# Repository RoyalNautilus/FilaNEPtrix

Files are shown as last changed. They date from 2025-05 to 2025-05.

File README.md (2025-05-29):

# FilaNEPtrix
This is a mod inspired by several projects to create a toolhead filament cutter for Neptune 4 and 4 Pro printers. This allows reliable and consistent multi-material and multicolor printing when paired with a MMU such as the [Box Turtle](https://github.com/ArmoredTurtle/BoxTurtle), [ERCF](https://github.com/Enraged-Rabbit-Community/ERCF_v2), [Pico MMU](https://github.com/lhndo/LH-Stinger/wiki/Pico-MMU), or others.

  * Please note that this is an *extremely* early release. Further optimization, iteration, and testing will be done over the next few weeks to hopefully turn this project into a stable and relatively hassle-free upgrade. 
  * If you have questions, would like to make suggestions, or notice any glaring issues to be resolved, please open an issue and let me know so I can get to work on it!
  
### Compatibility Note:
This was originally designed as a personal upgrade for my Neptune 4 Pro. While other models of Neptune 4 (or even Neptune 3) may function, alignment, tolerances, and features may differ just enough that the cutter may not operate as intended. Use at your own risk if you decide to try this on one of the other models!

## Gallery
*coming soon™*

## Recommended (and required) Paired Upgrades
### Toolhead Shroud - *MANDATORY*
Though there are many variants of the [OrzOrzOrz v5/6 Fan Shroud](https://www.printables.com/model/711424-elegoo-neptune-4promaxplus-fan-shroud-v5 "Printables"), the [SilencedFrost version](https://www.printables.com/model/905447-sf-3x5015-neptune-4-fan-mod-shroud-optimized-enhan "Printables") is (IMO) the ultimate version out so far. With compatibility with Beacon probes, many options for ADXL mounts, and the top-mounted bowden coupler options, not to mention the *stellar* cooling performance, there's really no way to go wrong with the upgrade.

To address the "Mandatory" tag, this is to say that FilaNEPtrix can only be installed on a shroud with heatset inserts or a similar mounting solution positioned in the same places on the top of the toolhead as SilencedFrost's. This is typically a pair of M3x5mm heat-set inserts located 5.5mm behind the *center* of the filament inlet, spaced 55mm apart. This placement allows full operation of the filament inlet, extruder manual release trigger, and exposed gear on the top, as well as leaving room for cooling fans.

### X-Axis

With the cutting motion applying great forces to the x-axis motion system, several X-axis upgrades will greatly help to prevent belt skipping. 
 * First, [layer.shifted (@Lamarc)'s X-Axis Double Shear Mod](https://www.printables.com/model/1222791-neptune-44pro-x-axis-double-shear-motor-upgrade "Printables").
   * This mod helps attach the X-axis motor pulley on both ends, allowing more tension without damage and preventing twisting from happening. (Side-benefit, *much* greater input shaper acceleration values in my testing!)
   * This will also allow for 3rd-party stepper motor upgrades, unlocking potential for much more reliable performance in the cutting action.

## BOM
*coming soon™*

## Recommended Print Settings
*coming soon™*

## Assembly
*coming soon™*

## Software Config & Tuning
*coming soon™*

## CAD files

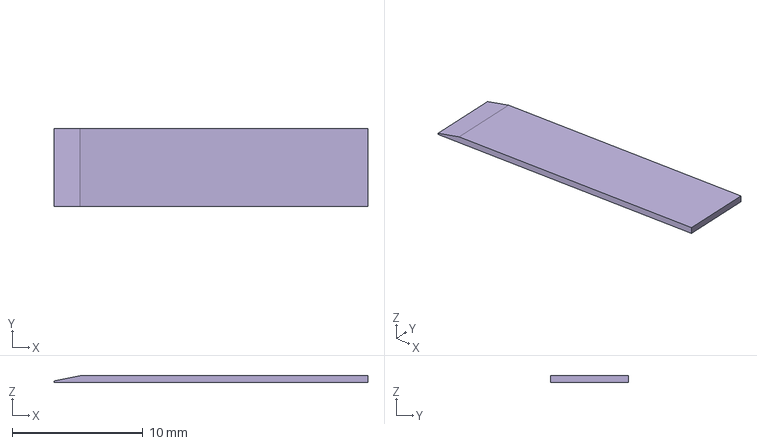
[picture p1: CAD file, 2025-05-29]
CAD/FilaNEPtrix.step
24.0 x 6.00 x 0.5 mm

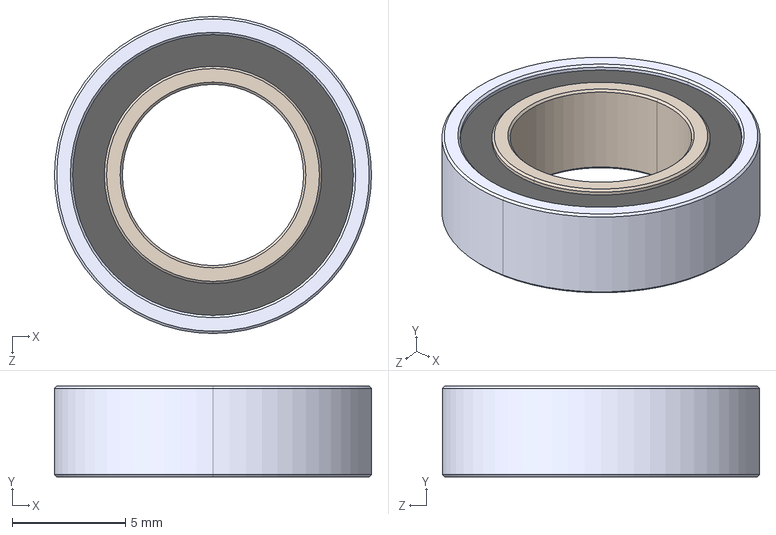
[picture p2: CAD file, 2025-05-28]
External Components/MR148-2RS Thrus Bearing- Thinhhouy.STEP
14.0 x 4.00 x 14.0 mm

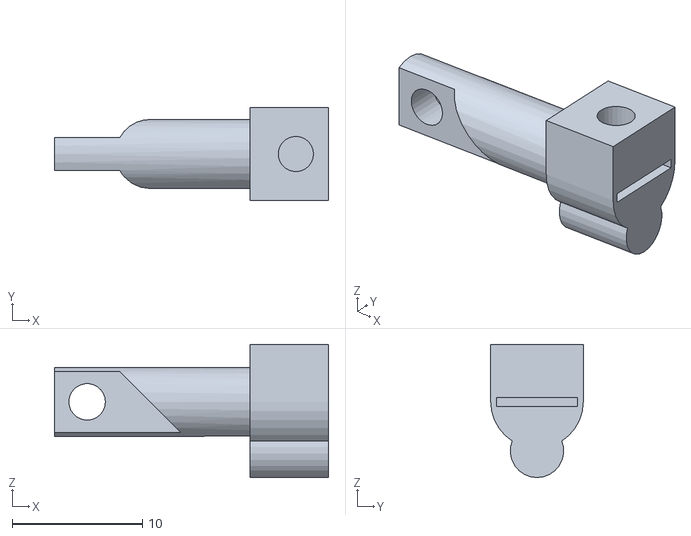
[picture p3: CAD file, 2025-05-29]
STLs/blade-mount-slider.stl
21.0 x 7.10 x 10.2

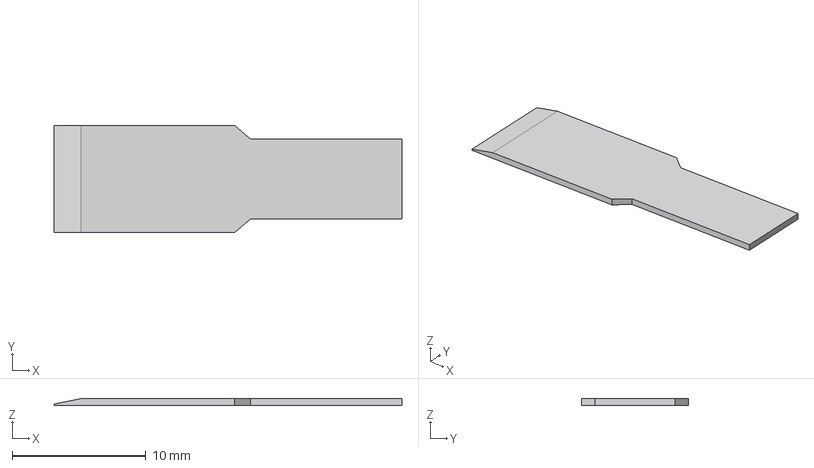
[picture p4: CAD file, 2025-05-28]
External Components/Hobby Knife Blade.step
26.0 x 8.00 x 0.5 mm

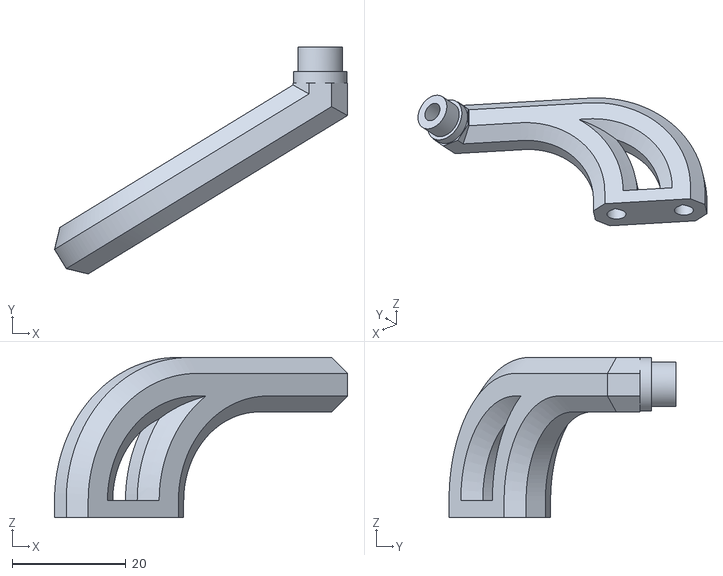
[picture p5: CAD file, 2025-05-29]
STLs/cutter-engager.stl
51.6 x 40.0 x 28.2

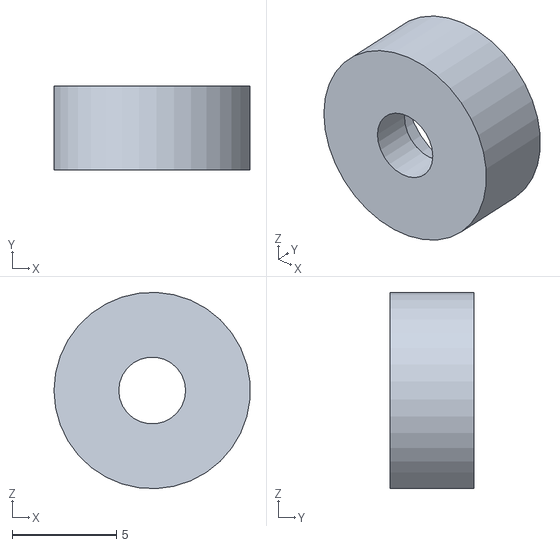
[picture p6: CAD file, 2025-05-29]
STLs/bearing-stopper.stl
9.38 x 4.00 x 9.39

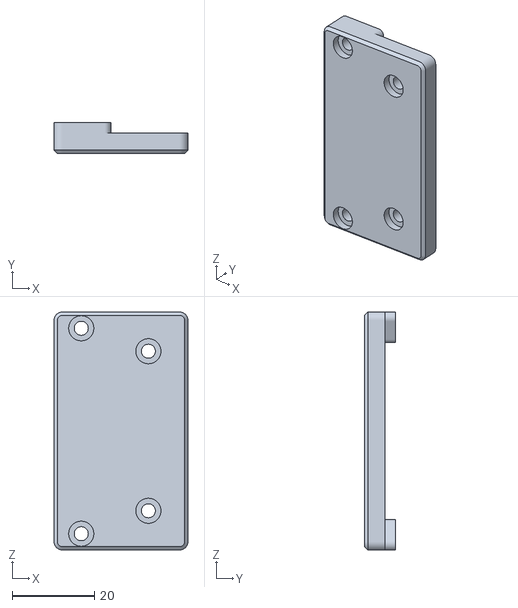
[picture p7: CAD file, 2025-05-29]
STLs/x-mount-back.stl
32.5 x 7.50 x 57.8

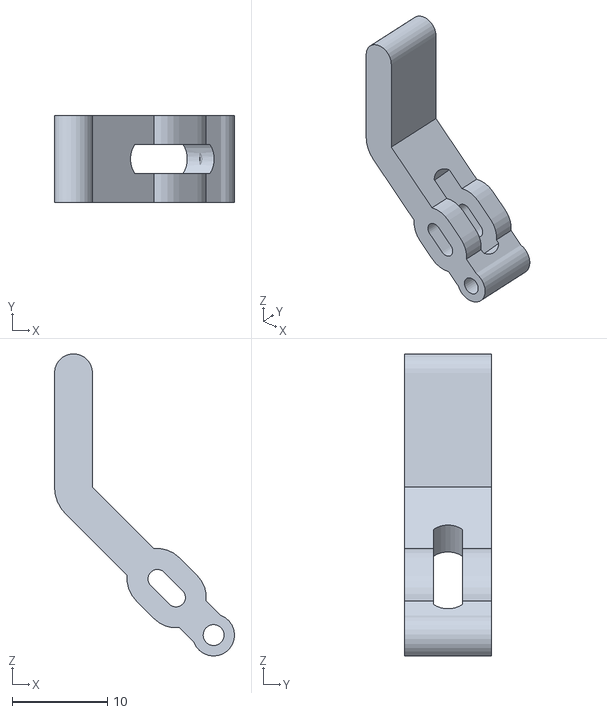
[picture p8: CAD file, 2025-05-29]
STLs/cutter-trigger.stl
18.9 x 9.10 x 31.7

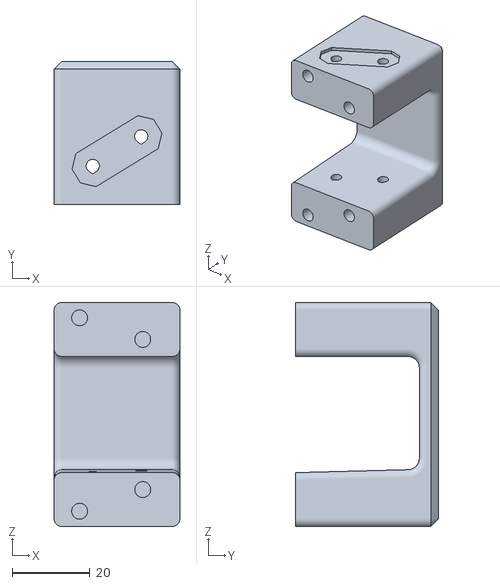
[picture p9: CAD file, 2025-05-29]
STLs/x-mount-front.stl
32.5 x 37.0 x 57.8

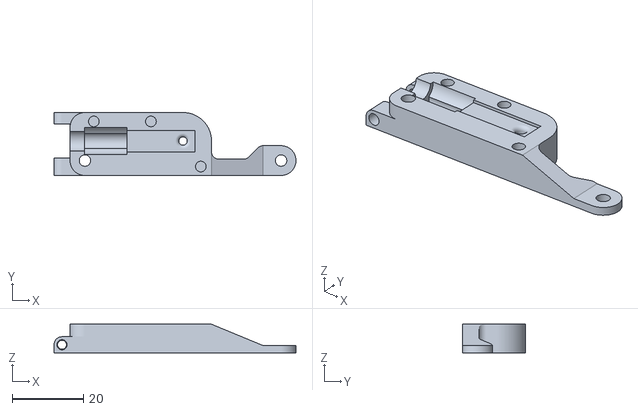
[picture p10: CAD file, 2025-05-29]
STLs/toolhead-mount.stl
67.9 x 17.6 x 8.00

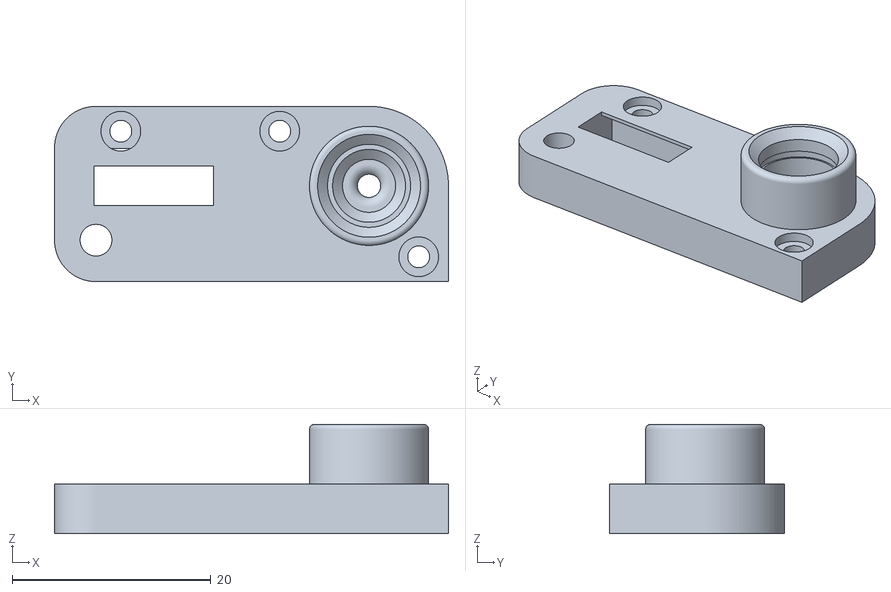
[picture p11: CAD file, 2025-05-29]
STLs/bowden-mount-ecas04.stl
39.7 x 17.6 x 11.0

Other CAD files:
CAD/FilaNEPtrix.FCStd

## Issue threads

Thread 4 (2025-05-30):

TODO: add more clearance for blade inside toolhead mount to allow complete tightening without binding the blade

RoyalNautilus, 2025-05-30:

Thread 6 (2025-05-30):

TODO: add servo option/compatibility to activate and deactivate cutter engager

RoyalNautilus, 2025-05-30:
Would allow for uninterrupted X-axis homing on the left side and remove the slight loss in build volume on the right side. Will need to see what's possible here.
Possible to re-use aux fan cable to make for an easy mod?

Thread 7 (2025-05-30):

TODO: N4Plus/Max variant

RoyalNautilus, 2025-05-30:
As I don't own either of these models, and Elegoo has made no CAD files for the N4 series, I will need somebody else to confirm dimensions and test

RoyalNautilus, 2025-07-24:
> Hey,
>
> I hope the project isn’t dead. I’m from Germany and using a translator, so I hope you still understand me correctly. I’m using the Neptune 4 Plus with the SilencedFrost fan shroud and the Pico MMU, and I’m currently testing your filament cutter, or rather, I’m still working on finishing the build properly. I’d love to contribute to the project. The dimensions seem to fit so far. However, I’m not sure how the lever is supposed to spring back on its own. Could you help me with that?

Hey!
It's not dead, I've just had an extremely busy couple of weeks at my day job.

I think I have the last iteration of design finished and ready to go that solves most of the issues I ran into previously. Just need to print it and test it out, then go through and fill out the BOM which I know is a big step missing at the moment.

To answer your question about the lever, there is a pocket in the toolhead-mount part that fits a small spring, before you insert the blade-mount-slider part. I believe the spring I used is from the FilamATtrix kit that came with my LDO Box Turtle kit, which looking at the BOM for that project seems to be a 0.5mm x 4mm x 25mm spring. According to those docs, a standard spring from a ball-point pen should be close enough to spec to be functional.

Hope that helps! I finally have a couple of free weekends coming up and will turn my attention back to finishing up all the missing parts of this project!

RoyalNautilus, 2025-07-24:
Also to note, I don't know how the dimensions of the Plus differ from the Pro, so the cutter-engager part may not line up exactly with the cutter-trigger as designed for the Pro.

derVampi, 2025-07-25:
Hey, thanks a lot for your reply! I'm glad to see things are moving forward and I'm excited about the upcoming improvements.

A spring? Why didn’t I think of that myself? 😅 I’ll give it a try. thanks in advance!
How can I help you with the measurements for the Neptune 4 Plus?
The lever isn’t perfectly centered, but it fits and cuts the filament when I move the printhead to the right.

derVampi, 2025-07-25:
The spring from a ballpoint pen fits perfectly. Thanks a lot for the tip! The cutting now works flawlessly. I just need to fine-tune it a bit so the filament change works automatically.

While doing that, I ran into a problem caused by my Eddy probe. During the bed level scan, the filament was cut. I temporarily solved it by slightly reducing the bed mesh on the X-axis.

derVampi, 2025-08-09:
Hey, everything's fine. I'm not the fastest at replying either 😅.

To be honest, I don't print that large, as I have the same warping issue with larger parts, so it doesn't bother me. It would probably work better with a closed build chamber.

The filament cutter is working perfectly at the moment. I just need to solve a few issues to ensure the filament passes the sensor, UBBI connector, etc. cleanly.

HutchMD, 2025-08-29:
I'm happy to see that there is hope for my dream of using my Neptune 4 Max with a Box Turtle.

I will be patiently waiting for a BoM list, and Assembly instructions!
Let me know if there's something I can do to help you test this on a N4 Max.

I am currently looking at shroud options that can fit my needs.
(I do have 2 5015 Blowers that OrzOrzOrz shroud are made for), but I also am trying to install a BTT Eddy Duo for the first time, so I'm currently at that stage.

Though I might have jumped the gun and purchased a Box Turtle kit.... so.... needless to say, I might be overwhelming myself on top of my normal job, LOL.

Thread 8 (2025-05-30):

Minor flex from cutter actuation, rolling the cutter housing around the X-axis.

RoyalNautilus, 2025-05-30:
Probably not great for long-term durability and reliability.

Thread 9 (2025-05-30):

TODO: more secure mounting of toolhead housing

RoyalNautilus, 2025-05-30:
Will try to remix SilencedFrost's toolhead to add more mounting points for a more rigid connection

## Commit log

2025-05-29 Re-organized folder structure, renamed to better suit git workflow, working name changed to "FilaNEPtrix"
    [BallBearing_8x22x7mm.STEP, Neptune Cutter Assembly v0.6.FCStd, Neptune Cutter v0.2.3mf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]
2025-05-29 General Organization and prep for public release
    [FilaNEPtrix.step, Hobby Knife Blade.step, MR148-2RS Thrus Bearing- Thinhhouy.STEP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]
2025-06-18 Updated FreeCAD file through Blade Slot for better parametric adjustment and avoiding TNP
2025-06-20 toolhead-mount fully parameterized
    Finished correcting references and attachments for toolhead-mount Body. Now all sketches only reference other sketches, and all sketch attachments modes are now based off of origin planes with offsets based on formulas and VarSets.
2025-07-01 bowden-mount-ecas04 fixed
    Now fully parametric and should be much more resilient to TNP issues down the line.
2025-07-01 fix blade--mount-slider
    Now fully parametric and should be resilient to TNP
